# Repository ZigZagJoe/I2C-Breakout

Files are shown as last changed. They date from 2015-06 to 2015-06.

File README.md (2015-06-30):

<h3>Breakout board w/  I2C controller PCA9665</h3> 
<br>
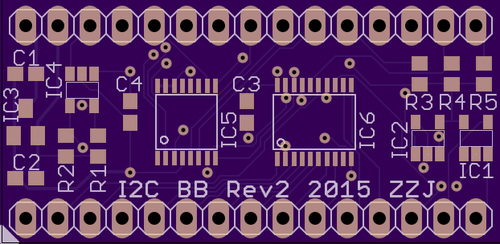
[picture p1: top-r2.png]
<br><a href="https://oshpark.com/profiles/ZigZagJoe"><br>Order PCB here!</a><br><br><b>Features:</b><br>
100khz to 1mhz I2C bus<br>
5V-tolerant I/O<br>
3.3v VCC<br>
68 byte buffer<br><br>
30 pins (2x15),  0.1" spacing,  0.6" pin width<br>2 layer, 1.55" x 0.76" (39.37x19.20 mm)<br>

<h4>Optional parts:</h4>
<b>3.3v regulator MCP1700</b>, 3.5v-6v Vin, 250ma<br>

<b>I2C-SPI bridge SC18IS602</b><br>
<b>I2C ADC MCP3221A</b>, 1ch, 12bit<br>
<b>I2C EEPROM</b>, SOT23-5<br>
<b>OC driver for /CS -> /DTACK</b><br>

<br><b>Changelog</b><br>
<b>Rev2:</b> Fixed ADC layout (transposed Vcc and Gnd)</br>

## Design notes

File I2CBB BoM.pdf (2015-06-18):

Part # | Desc | Price | Cnt | Sum | Link | Package
PCA9665APW | I2C controller | $3.13 | 1 | $3.13 | http://www.digikey.co (http://www.digikey.com/product-detail/en/PCA9665APW,118/568-8587-1-ND/2791899) | TSSOP-20
SC18IS602BI | I2C-SPI bridge | $2.88 | 1 | $2.88 | http://www.digikey.co (http://www.digikey.com/product-detail/en/SC18IS602BIPW,128/568-10300-1-ND/4162463) | TSSOP-16
24AA64T-I/OT | 8k x 8 I2C EEPROM | $0.43 | 1 | $0.43 | http://www.digikey.co (http://www.digikey.com/product-detail/en/24AA64T-I%2FOT/24AA64T-I%2FOTCT-ND/2060066) | SOT-23-5
MCP3221A5T- I2C 1CH 12BIT SAR ADC | | $1.73 | 1 | $1.73 | http://www.digikey.co (http://www.digikey.com/product-detail/en/MCP3221A5T-E%2FOT/MCP3221A5T-E%2FOTCT-ND/1979809) | SOT-23-5
MCP1700T-33 | 3.3V regulator | $0.44 | 1 | $0.44 | http://www.digikey.co (http://www.digikey.com/product-detail/en/MCP1700T-3302E%2FTT/MCP1700T3302ETTCT-ND/652677) | SOT-23-3
NC7WZ07P6X | OC buffer | $0.49 | 1 | $0.49 | http://www.digikey.co (http://www.digikey.com/product-detail/en/SN74LVC1G07DBVR/296-8485-1-ND/377454) | SOT-23-5
| 2k resistor (SCL, SDA pull | $0.01 | 2 | $0.02 | http://www.digikey.com/ (http://www.digikey.com/product-detail/en/RC0603JR-072KL/311-2.0KGRCT-ND/729673) | 0603
| 4.7k resistor (INT, RESET | $0.01 | 3 | $0.03 | http://www.digikey.com/ (http://www.digikey.com/product-detail/en/RC0603JR-074K7L/311-4.7KGRCT-ND/729732) | 0603
| 1uf cap (regulator in/out) | $0.03 | 2 | $0.06 | http://www.digikey.com/ (http://www.digikey.com/product-detail/en/CC0603KRX5R6BB105/311-1443-1-ND/2833749) | 0603
| 0.1uf cap (decoupling) | $0.02 | 2 | $0.03 | http://www.digikey.com/ (http://www.digikey.com/product-detail/en/GRM188R71C104KA01D/490-1532-1-ND/587771) | 0603
| 1x30 header | $0.43 | 1 | $0.43 | http://www.digikey.com/ (http://www.digikey.com/product-detail/en/PREC030SAAN-RC/S1012EC-30-ND/2774824) | .1" pitch
| PCB | $1.95 | 1 | $1.95 | https://oshpark.com/ | n/a
Total: | $11.6

I2C/SPI Breakout Board

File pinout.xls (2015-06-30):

Eagle header pins: | 15 | 14 | 13 | 12 | 11 | 10 | 9 | 8 | 7 | 6 | 5 | 4 | 3 | 2 | 1
 |  |  | Analog | SPI |  |  |  |  |  |  |  | I2C |  |  | Host
Desc | VCC | 3V3 | A_IN | /SS3 | /SS2 | /SS1 | /SS0 | SPICLK | MISO | MOSI | /INT2 | SCL | SDA | /INT1 | /RESET
Pin | 30 | 29 | 28 | 27 | 26 | 25 | 24 | 23 | 22 | 21 | 20 | 19 | 18 | 17 | 16
Pin | 1 | 2 | 3 | 4 | 5 | 6 | 7 | 8 | 9 | 10 | 11 | 12 | 13 | 14 | 15
Desc | A0 | A1 | D0 | D1 | D2 | D3 | D4 | D5 | D6 | D7 | /RD | /WR | /CS | /DTACK | GND
 | Host Interface

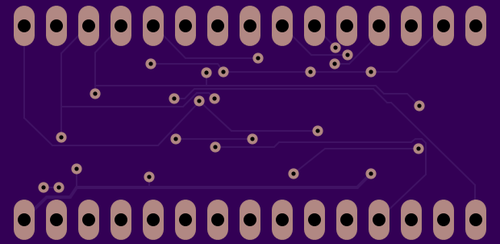
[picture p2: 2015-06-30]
bot-r2.png

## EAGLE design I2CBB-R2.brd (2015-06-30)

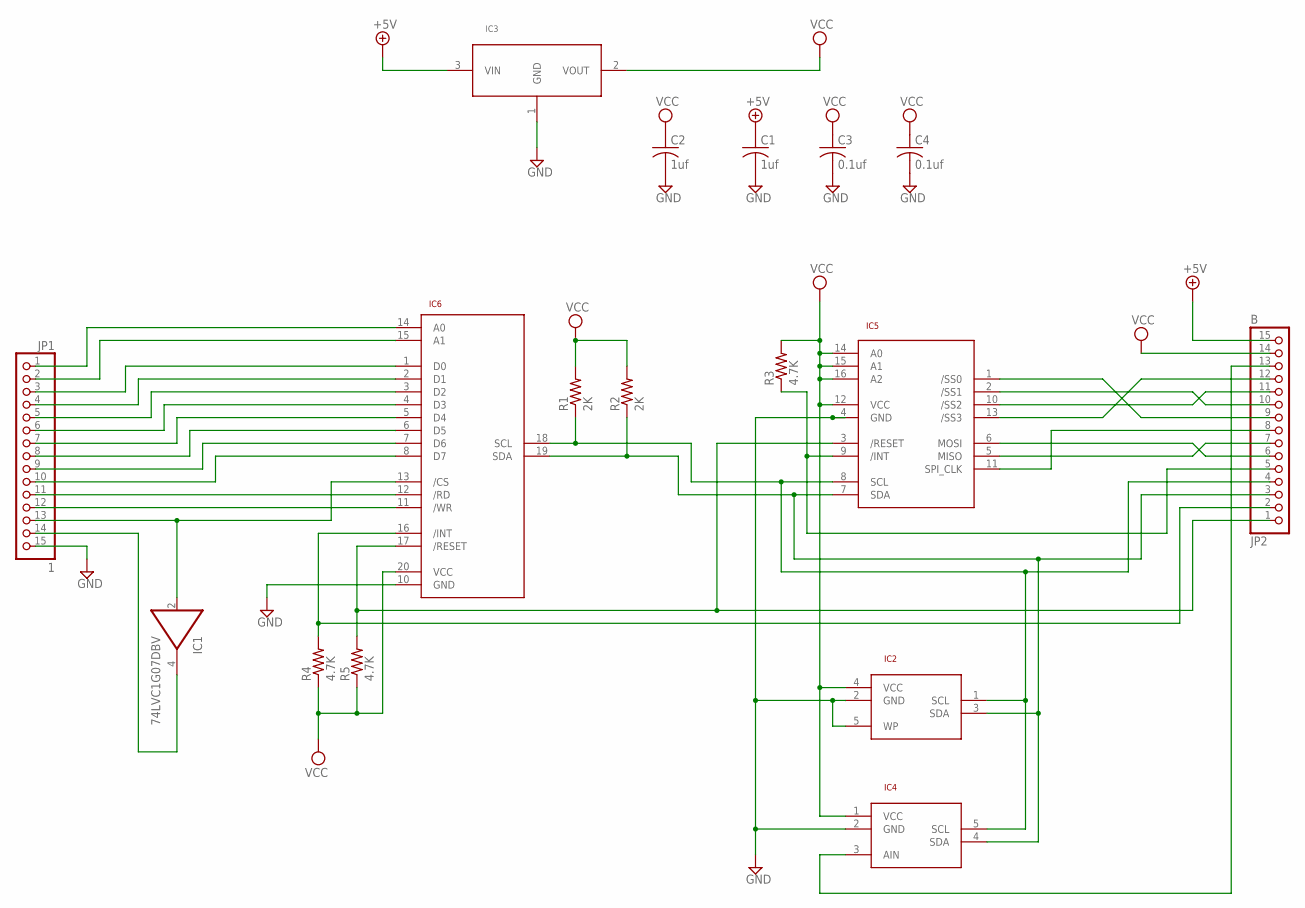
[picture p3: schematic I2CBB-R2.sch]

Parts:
C1, C2: 1uf; C0603
C3, C4: 0.1uf; C0603
IC1: 74LVC1G07DBV; SOT23-5
IC2: 24AA64T; SOT23-5
IC3: MCP1700T; SOT23
IC4: MCP3221; SOT23-5
IC5: SC18IS602; TSSOP16
IC6: PCA9665; TSSOP20
JP1: 1; 1X15
JP2: B; 1X15
R1, R2: 2K; R0603
R3, R4, R5: 4.7K; R0603

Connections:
+5V: C1.1, IC3.3 (VIN), JP2.15
/INTI2C: IC6.16 (/INT), JP2.2, R4.2
AIN: IC4.3 (AIN), JP2.13
GND: C1.2, C2.2, C3.2, C4.2, IC1.3 (GND), IC2.2 (GND), IC2.5 (WP), IC3.1 (GND), IC4.2 (GND), IC5.4 (GND), IC6.10 (GND), JP1.15
unnamed: IC1.2 (I), IC6.13 (/CS), JP1.13
unnamed: IC1.4 (O), JP1.14
unnamed: IC6.11 (/WR), JP1.12
unnamed: IC6.12 (/RD), JP1.11
unnamed: IC6.14 (A0), JP1.1
unnamed: IC6.15 (A1), JP1.2
unnamed: IC6.1 (D0), JP1.3
unnamed: IC6.2 (D1), JP1.4
unnamed: IC6.3 (D2), JP1.5
unnamed: IC6.4 (D3), JP1.6
unnamed: IC6.5 (D4), JP1.7
unnamed: IC6.6 (D5), JP1.8
unnamed: IC6.7 (D6), JP1.9
unnamed: IC6.8 (D7), JP1.10
unnamed: IC5.9 (/INT), JP2.5, R3.1
unnamed: IC5.10 (/SS2), JP2.11
unnamed: IC5.2 (/SS1), JP2.10
unnamed: IC5.1 (/SS0), JP2.9
unnamed: IC5.13 (/SS3), JP2.12
unnamed: IC5.5 (MISO), JP2.7
unnamed: IC5.6 (MOSI), JP2.6
unnamed: IC5.11 (SPI_CLK), JP2.8
RESET: IC5.3 (/RESET), IC6.17 (/RESET), JP2.1, R5.2
SCL: IC2.1 (SCL), IC4.5 (SCL), IC5.8 (SCL), IC6.18 (SCL), JP2.4, R1.1
SDA: IC2.3 (SDA), IC4.4 (SDA), IC5.7 (SDA), IC6.19 (SDA), JP2.3, R2.1
VCC: C2.1, C3.1, C4.1, IC1.5 (VCC), IC2.4 (VCC), IC3.2 (VOUT), IC4.1 (VCC), IC5.12 (VCC), IC5.14 (A0), IC5.15 (A1), IC5.16 (A2), IC6.20 (VCC), JP2.14, R1.2, R2.2, R3.2, R4.1, R5.1

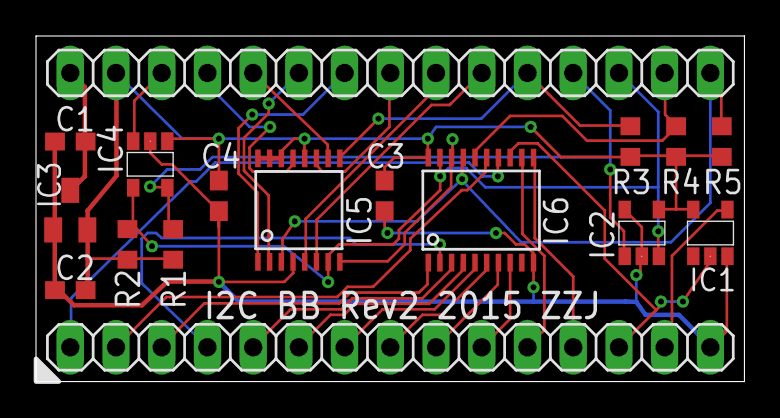
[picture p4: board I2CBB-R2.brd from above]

Board: 2 copper layers, 39.4 x 19.2 mm, 17 parts (0 on the bottom side), 30 nets.

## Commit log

2015-06-22 Add OSHPARK link to order PCBs
2015-06-27 Fix MCP3221 layout - transposed GND and Vcc
2015-06-27 Add rev2 - fix transposed vcc and gnd on MCP3221
    [I2CBB-R2.brd, I2CBB-R2.sch]
2015-06-30 Better trace routing on ADC
    [I2CBB-R2.brd]
2015-06-30 Add borders and class to pinout, and add picture
    [pinout.xls]
